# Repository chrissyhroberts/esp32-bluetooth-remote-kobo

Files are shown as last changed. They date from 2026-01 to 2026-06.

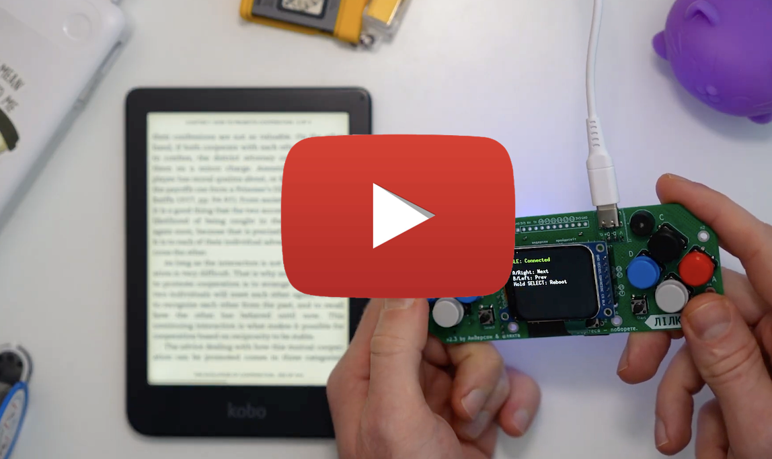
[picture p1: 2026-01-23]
img/lilka-kobo-demo-video.png

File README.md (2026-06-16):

# Kobo BLE Page Turner

A simple Bluetooth page-turning remote for Kobo e-readers built using an ESP32, two mechanical keyboard switches, and a rechargeable LiPo battery.

The device acts as a Bluetooth HID keyboard and sends left and right arrow key presses to a Kobo reader. It is designed as a compact handheld remote that can be comfortably operated using the index and middle fingers while reading.

Also works as a slide-clicker for presenting in powerpoint etc. on a laptop or phone. 

WhatsApp Image 2026-06-16 at 10 27 49
WhatsApp Image 2026-06-16 at 10 27 48 (1)

## Demo

https://github.com/user-attachments/assets/7c18b657-2313-463f-bc3e-a1ec03a47499

## Features

* Bluetooth Low Energy (BLE) HID keyboard
* Compatible with Kobo e-readers that support Bluetooth keyboards
* Two-button interface:

  * Next page
  * Previous page
* Rechargeable LiPo battery support
* USB charging via Adafruit HUZZAH32 Feather
* Mechanical keyboard switches for improved tactile feedback
* Open-source hardware and software
* Fully self-contained handheld design

## Hardware

### Current Build

| Component | Description |
| --- | --- |
| Microcontroller | Adafruit HUZZAH32 Feather ESP32 |
| Battery | 3.7V LiPo (150–500 mAh recommended) |
| Buttons | 2 × MX-compatible mechanical keyboard switches |
| Keycaps | Standard MX-compatible keycaps |
| Enclosure | Custom 3D printed enclosure |
| Charging | Integrated Feather LiPo charger |

### Wiring

| GPIO | Function |
| --- | --- |
| GPIO14 | Next page |
| GPIO27 | Previous page |

Connect each switch between the GPIO pin and GND.

```text
GPIO14 ---- Switch ---- GND

GPIO27 ---- Switch ---- GND
```

No external resistors are required because the firmware uses the ESP32's internal pull-up resistors.

### Battery

The current design uses a single-cell 3.7V LiPo battery connected directly to the Feather JST connector.

Recommended capacities:

| Capacity | Notes |
| --- | --- |
| 150 mAh  | Compact, preferred for final build |
| 300 mAh  | Good compromise |
| 500 mAh  | Longer runtime |
| 1200 mAh | Works but physically large |

## Enclosure

The enclosure is designed around:

* Adafruit HUZZAH32 Feather
* Two MX switches mounted in a side wall
* Small LiPo battery
* USB access for charging and firmware updates

The intended grip places one long side of the enclosure against the index and middle fingers, allowing page turns without changing grip.

```text
      SW1     SW2
       ↓       ↓

 ┌──────────────────┐
 │                  │
 │  Feather + LiPo  │
 │                  │
 └──────────────────┘
```

Current design goals:

* Approximately 80 × 32 × 20 mm
* Lightweight
* Rechargeable
* One-handed operation
* Easily printable without support

## Firmware

The firmware is written using Arduino and PlatformIO.

The device advertises as:

```text
KoboPageTurner
```

and appears to the Kobo as a Bluetooth keyboard.

### Building

```bash
python3 -m platformio run -e huzzah32
```

### Uploading

```bash
python3 -m platformio run -e huzzah32 -t upload
```

### Serial Monitor

```bash
python3 -m platformio device monitor -b 115200
```

## Pairing

1. Power on the device.
2. Open Bluetooth settings on the Kobo.
3. Search for:

```text
KoboPageTurner
```

4. Pair and connect.
5. Open a book and test page turns.

## Power Management

The current firmware remains continuously connected.

Planned behaviour:

```text
Button press
    ↓
Wake ESP32
    ↓
Start BLE
    ↓
Connect to Kobo
    ↓
Remain active
    ↓
5 minutes inactivity
    ↓
Deep sleep
```

This should allow excellent battery life even with a small 150 mAh LiPo cell.

## Development History

The project was initially prototyped using an ESP32-C3 SuperMini before being migrated to an Adafruit HUZZAH32 Feather to take advantage of:

* Integrated LiPo charging
* JST battery connector
* Simplified hardware
* Easier prototyping

## Acknowledgements

### Firmware

This project builds upon and adapts the work of:

* https://github.com/tkanov/esp32-bluetooth-remote-kobo

The original project targets the Lilka ESP32 platform and demonstrates BLE page turning for Kobo devices. This project adapts the concept for the Adafruit HUZZAH32 Feather and a custom handheld enclosure.

### Enclosure

The enclosure design was inspired by:

* https://www.thingiverse.com/thing:3824089

which provided the basis for Cherry MX switch mounting and plate geometry used during enclosure development.

## License

MIT License.

This repository contains original work together with adaptations of MIT-licensed open-source software and design concepts. Attribution to upstream projects is provided in the acknowledgements section.

## Future Work

* Deep sleep support
* Wake on button press
* Battery level monitoring
* Status LED indication
* Improved enclosure ergonomics
* Smaller PCB-based hardware revision
* Optional support for additional e-reader platforms

# Changelog

All notable changes to this project will be documented in this file.

The format is based on Keep a Changelog.

## [0.2.0] - 2026-06-13

### Added

* Migrated project to Adafruit HUZZAH32 Feather ESP32.
* Added support for LiPo battery operation using onboard JST connector.
* Added support for integrated USB charging via Feather hardware.
* Added custom 3D printed handheld enclosure.
* Added support for MX-compatible mechanical keyboard switches.
* Added serial debugging messages for button presses and BLE connection state.
* Added documentation and build instructions.

### Changed

* Replaced ESP32-C3 SuperMini hardware with HUZZAH32 Feather.
* Simplified hardware architecture by eliminating external charger modules.
* Updated button assignments:

  * GPIO14 → Next page
  * GPIO27 → Previous page
* Redesigned enclosure for side-mounted switch operation using index and middle fingers.
* Optimised device layout around Feather form factor and LiPo battery.

### Fixed

* Resolved BLE pairing and connection issues during migration from ESP32-C3.
* Confirmed compatibility with Kobo Bluetooth keyboard input.
* Verified HID arrow key transmission on HUZZAH32 platform.

## [0.1.0] - 2026-06-13

### Added

* Initial proof-of-concept implementation based on:

  * https://github.com/tkanov/esp32-bluetooth-remote-kobo
* BLE HID keyboard functionality.
* Kobo page-turn support using left and right arrow keys.
* ESP32-C3 SuperMini firmware build environment.
* PlatformIO build and upload workflow.
* Basic two-button operation:

  * Next page
  * Previous page
* BLE bonding and security configuration.
* Reboot button support.
* Serial status reporting.

### Hardware

* ESP32-C3 SuperMini.
* Two momentary push-buttons connected directly to GPIO inputs.
* USB-powered operation.

## Planned

### [0.3.0]

* Deep sleep support.
* Wake on button press.
* Automatic sleep after inactivity.
* Battery-life optimisation.
* Battery status indication.
* Improved enclosure ergonomics.
* Finalised printable enclosure design.

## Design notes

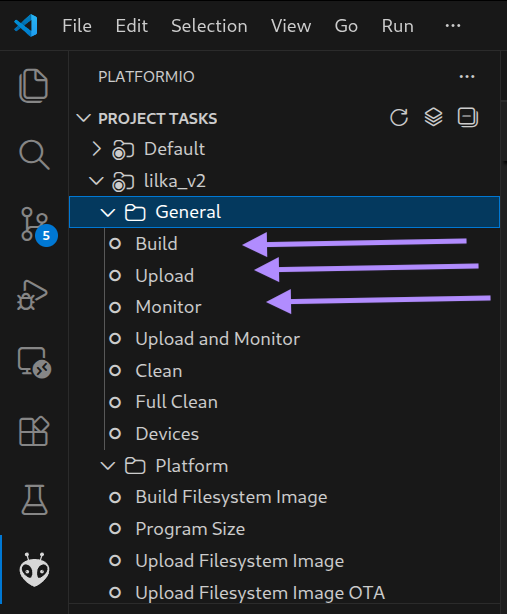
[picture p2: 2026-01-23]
img/vscode-platformio.png

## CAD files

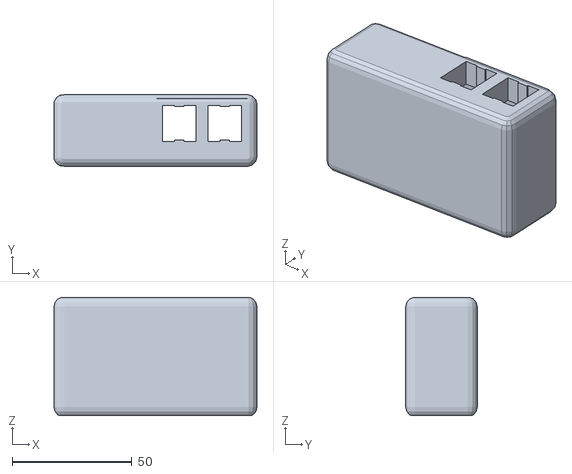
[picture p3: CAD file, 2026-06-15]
Enclosure_parametric.stl
84.9 x 29.9 x 49.4

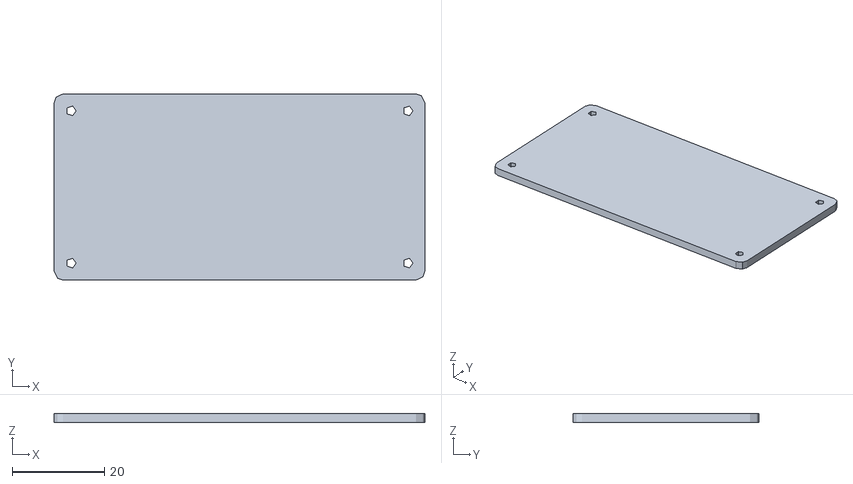
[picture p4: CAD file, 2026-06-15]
Enclosure_parametric_lid.stl
80.4 x 40.4 x 2.00

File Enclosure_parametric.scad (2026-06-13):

/* Kobo BLE Page Turner Enclosure
   Side-face MX switch version
   Hold with narrow long side against index/middle fingers.
*/

$fn = 48;

// ---------- Main dimensions ----------
case_w = 80;      // length
case_h = 40;      // width
case_d = 20;      // thickness / height

wall = 2;
corner_r = 5;

// ---------- MX side switch settings ----------
mx_cut = 14.2;
mx_spacing = 26;          // distance between switch centres along length
mx_z = 2;                 // vertical position on side face
switch_side_y = case_h/2; // switches on upper long side

// ---------- USB cutout on short end ----------
usb_w = 11;
usb_h = 7;
usb_x = case_w/2;

// ---------- Lid ----------
lid_thick = 2;
lid_gap = 0.35;
lip_h = 3;

// ---------- Helpers ----------
module rounded_box(w, h, d, r) {
    hull() {
        for (x=[-w/2+r, w/2-r])
        for (y=[-h/2+r, h/2-r])
            translate([x,y,0])
                cylinder(h=d, r=r, center=true);
    }
}

// MX cutout projected through side wall.
// Shape dimensions: x = switch width along case length,
// z = switch height, y = depth through wall.
module mx_side_cutout() {
    cube([mx_cut, wall + 8, mx_cut], center=true);
}

// ---------- Top shell ----------
module top_shell() {
    difference() {
        // outer body
        rounded_box(case_w, case_h, case_d, corner_r);

        // hollow interior, open from bottom
        translate([0,0,-wall])
            rounded_box(
                case_w - 2*wall,
                case_h - 2*wall,
                case_d,
                max(corner_r - wall, 1)
            );

        // side-face MX cutouts
        translate([-mx_spacing/2, switch_side_y, mx_z])
            mx_side_cutout();

        translate([ mx_spacing/2, switch_side_y, mx_z])
            mx_side_cutout();

        // USB cutout on right short end
        translate([usb_x, 0, -2])
            cube([wall + 3, usb_w, usb_h], center=true);
    }
}

// ---------- Bottom lid ----------
module bottom_lid() {
    union() {
        rounded_box(case_w, case_h, lid_thick, corner_r);

        translate([0,0,lid_thick/2 + lip_h/2])
        difference() {
            rounded_box(
                case_w - 2*wall - lid_gap,
                case_h - 2*wall - lid_gap,
                lip_h,
                max(corner_r - wall, 1)
            );

            rounded_box(
                case_w - 2*wall - 4,
                case_h - 2*wall - 4,
                lip_h + 1,
                max(corner_r - wall - 1, 1)
            );
        }
    }
}

// ---------- Build ----------
top_shell();

translate([0, 48, -case_d/2 + lid_thick/2])
    bottom_lid();

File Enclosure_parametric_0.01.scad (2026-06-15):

/*[Station]*/
rows=2;
columns=1;
// Could be made thinner but then you should add legs. Make sure the total height/thickness is 9 or more or else the switches will touch the ground.
caseThickness=9;
switch="MX"; // ["MX","ALPS"]
showSwitch=false;

/*[Legs]*/
legs=false;
legWidth=3;
legLength=3;
legHeight=6;

/*[Puzzle]*/
puzzle=false;
leftPuzzle=true;
rightPuzzle=true;
frontPuzzle=true;
backPuzzle=true;



/*[Danger zone]*/
// Measured from key cap center to key cap center
space=19.04;
plateLength=space*1.089;

/*[MX settings]*/
MX_cutXSize=14;
MX_cutYSize=15;
MX_notchX=4;
MX_notchY=0.50;

/*[ALPS settings]*/
ALPS_cutXSize=12.8;
ALPS_cutYSize=16.0;

function legZ(thickness,legHeight) = -(thickness*0.5+legHeight*0.5);

module MXSwitch(){
	// Awesome Cherry MX model created by gcb
	// Lib: Cherry MX switch - reference
	// Download here: https://www.thingiverse.com/thing:421524
	//  p=cherrySize/2+0.53;
	translate([0,0,13.2])
  rotate([0,0,-90])
		import("switch_mx.stl");
}

module ALPSSwitch(){
  // ALPS model created by qwelyt (me)
  // Lib: ALPS switch - reference
  // Download here: https://www.thingiverse.com/thing:3829342
  translate([0,0,-2])
  rotate([0,0,0])
  import("ALPS-switch.stl");
}

module leg(){
  cube([legWidth,legLength,legHeight],center=true);
}


module legs(thickness,rows,cols, row, col){
  x=(space*0.5-legWidth*0.5);
  y=(plateLength*0.5-legLength*0.5);
  z=legZ(thickness,legHeight);
  
  translate([0,0,0])translate([-x,-y,z])leg();
  translate([space*rows,0,0])translate([x,-y,z])leg();
  translate([0,space*cols,0])translate([-x,y,z])leg();
  translate([space*rows,space*cols,0])translate([x,y,z])leg();
  
}

module KeyPlate(w=space,l=plateLength,h=caseThickness,center=true){
	cube([w,l,h],center=center);
}

module MXCut(thickness,x,y,MX_notchX,MX_notchY){
  union(){
    difference(){
      cube([x,y,thickness+2],center=true);
      
      translate([0,y/2,0])
      cube([MX_notchX,MX_notchY,thickness+3],center=true);
      
      translate([0,-y/2,0])
      cube([MX_notchX,MX_notchY,thickness+3],center=true);
    }
  }
}

module ALPSCut(thickness){
  cube([ALPS_cutXSize,ALPS_cutYSize,thickness+2],center=true);
}

module puzzleCut(thickness,hook){
  size = hook ? 9 : 10;
  move = hook ? 1 : 0;
  difference(){
    translate([0,0,0])rotate([0,0,45])cube([size,size,thickness],center=true);
    
    translate([0,size*0.4,0])cube([size*2,size,thickness+2],center=true);
    
    translate([0,-((size*0.8)+move),0])cube([size*2,size,thickness+2],center=true);
  }
}

module plate(){
   union(){
    for(r=[0:rows-1]){
      for(c=[0:columns-1]){
        translate([space*r, space*c,0]){
          difference(){
            KeyPlate();
            if(switch == "MX"){
              MXCut(caseThickness,MX_cutXSize,MX_cutYSize,MX_notchX,MX_notchY*2);
            } else if(switch == "ALPS"){
              ALPSCut(caseThickness);
            } else {
              cube([space*0.8,space*0.8,caseThickness+2],center=true);
            }
          }
          if(showSwitch){
            if(switch == "MX"){
              #translate([0,0,caseThickness/2])MXSwitch();
            } else if(switch == "ALPS"){
              #translate([0,0,caseThickness/2])ALPSSwitch();
            } else {
              #translate([0,0,caseThickness/2])
              cube([space*0.8,space*0.8,caseThickness+2],center=true);
            }
          }
          
          
        }
      }
    }
  }
}

module build_swithes(){
  union(){
    if(puzzle){
      difference(){
        plate();
        if(backPuzzle){
          translate([0,-space*0.39,0])puzzleCut(caseThickness+2,false);
          
          translate([space*(rows-1),-space*0.39,0])puzzleCut(caseThickness+2,false);
        }
    
        if(rightPuzzle){
          translate([-space*0.346,0,0])rotate([0,0,-90])puzzleCut(caseThickness+2,false);
          
          translate([-space*0.346,space*(cols-1),0])rotate([0,0,-90])puzzleCut(caseThickness+2,false);
        }
      }
      
      if(frontPuzzle){
        translate([0,space*cols-space*0.3,0])puzzleCut(caseThickness,true);
        
        translate([space*(rows-1),space*cols-space*0.3,0])puzzleCut(caseThickness,true);
      }
      
      if(leftPuzzle){
        translate([space*rows-space*0.35,0,0])rotate([0,0,-90])puzzleCut(caseThickness,true);
        
        translate([space*rows-space*0.35,space*(cols-1),0])rotate([0,0,-90])puzzleCut(caseThickness,true);
      }
      
    } else {
      plate();
    }
 
    if(legs){
      legs(caseThickness,rows-1,cols-1,0,0);
    }
  }
}




case_w = 85;
case_h = 45;
case_d = 20;
wall = 2;
r = 4;

module rounded_cube(size=[70,40,20], r=4) {
    minkowski() {
        cube([
            size[0] - 2*r,
            size[1] - 2*r,
            size[2] - 2*r
        ], center=true);
        sphere(r=r);
    }
}

module hollow_body() {
    difference() {
        rounded_cube([case_w, case_h, case_d], r);

        translate([0,0,-wall])
            rounded_cube([
                case_w - 2*wall,
                case_h - 2*wall,
                case_d
            ], max(r-wall,1));
    }
}

module switch_holes_only() {
    for(rw=[0:rows-1]) {
        for(cl=[0:columns-1]) {
            translate([space*rw, space*cl, 6])
                MXCut(caseThickness + 4,
                      MX_cutXSize,
                      MX_cutYSize,
                      MX_notchX,
                      MX_notchY*2);
        }
    }
}

// ---------- Feather mount ----------
feather_w = 22.86;
feather_l = 50.8;
feather_hole_d = 2.6;      // clearance for M2-ish screw, tweak if needed
standoff_d = 5.5;
standoff_h = 12;
standoff_z = -case_d/2 + wall + standoff_h/2;

// Approximate mounting hole positions.
// Tune after a print if needed.
feather_hole_x = feather_l/2 - 2.54;
feather_hole_y = feather_w/2 - 2.54;

// Place Feather lengthwise in the case.
// Shift if USB is not aligned.
feather_x_offset = 2;
feather_y_offset = 0;

module feather_standoff(x, y) {
    translate([x + feather_x_offset, y + feather_y_offset, standoff_z])
    difference() {
        cylinder(h=standoff_h, d=standoff_d, center=true);
        cylinder(h=standoff_h + 1, d=feather_hole_d, center=true);
    }
}

module feather_mounts() {
    feather_standoff(-feather_hole_x, -feather_hole_y);
    feather_standoff( feather_hole_x, -feather_hole_y);
    feather_standoff(-feather_hole_x,  feather_hole_y);
    feather_standoff( feather_hole_x,  feather_hole_y);
}




// ---------- Lid screw mounts ----------
lid_screw_d = 2.2;       // hole in lid, clearance for M2
boss_hole_d = 1.6;       // pilot hole in case boss for M2 self-tapper
boss_d = 5.5;
boss_h = 17;

screw_x = case_w/2 - 6;
screw_y = case_h/2 - 6;

module screw_positions() {
    for (x=[-screw_x, screw_x])
    for (y=[-screw_y, screw_y])
        translate([x,y,0])
            children();
}

module case_screw_bosses() {
    screw_positions()
        translate([0,0,-case_d/2 + wall + boss_h/2])
        difference() {
            cylinder(h=boss_h, d=boss_d, center=true);
            cylinder(h=boss_h + 1, d=boss_hole_d, center=true);
        }
}

module lid_screw_holes() {
    screw_positions()
        cylinder(h=lid_thick + 1, d=lid_screw_d, center=true);
}


// ---------- USB slot ----------
// Micro USB on short end of HUZZAH32.
// Increase width/height if your cable plug is chunky.
usb_slot_w = 12;
usb_slot_h = 8;
usb_slot_z = -1;
usb_slot_x = case_w/2;

module usb_slot() {
    translate([usb_slot_x, feather_y_offset, usb_slot_z])
        cube([wall + 4, usb_slot_w, usb_slot_h], center=true);
}

module shell() {
    difference() {
        union() {
    hollow_body();

    translate([0,0,5])
        build_swithes();

    translate([0,-4,5])
        feather_mounts();

    case_screw_bosses();
}

        // cut only switch holes
        switch_holes_only();

        // clearance below switches
        translate([space/2, 0, -1])
            cube([space*1.8, plateLength*0.8, 10], center=true);

        // USB access slot on short edge
        translate([0,0,-2.5])usb_slot();
    }
}



// ---------- Lid ----------
lid_thick = 2;
lid_clearance = 0.6;   // increase if too tight
lid_r = r - wall;      // matches inner corner radius

lid_w = case_w - 2*wall - lid_clearance;
lid_h = case_h - 2*wall - lid_clearance;

module rounded_rect_2d(w, h, rad) {
    offset(r=rad)
        square([w - 2*rad, h - 2*rad], center=true);
}

module lid() {
    difference() {
        linear_extrude(height=lid_thick, center=true)
            rounded_rect_2d(lid_w, lid_h, lid_r);

        lid_screw_holes();
    }
}


//shell();

translate([0, 0, -case_d/2 + lid_thick/2])
translate([0,55,18])lid();

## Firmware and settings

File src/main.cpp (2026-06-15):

#include <Arduino.h>
#include <BleKeyboard.h>
#include <BLEDevice.h>
#include <BLESecurity.h>
#include "esp_sleep.h"

static const int NEXT_PIN = 14;
static const int PREV_PIN = 27;

static const uint32_t SLEEP_AFTER_MS = 5UL * 60UL * 1000UL;

BleKeyboard bleKeyboard("KoboPageTurner");

static uint32_t lastActivityMs = 0;

static void setupBleSecurityNoMitm() {
  auto *sec = new BLESecurity();

  sec->setAuthenticationMode(ESP_LE_AUTH_BOND);
  sec->setCapability(ESP_IO_CAP_NONE);
  sec->setKeySize(16);

  sec->setInitEncryptionKey(ESP_BLE_ENC_KEY_MASK | ESP_BLE_ID_KEY_MASK);
  sec->setRespEncryptionKey(ESP_BLE_ENC_KEY_MASK | ESP_BLE_ID_KEY_MASK);
}

static bool fell(int pin) {
  static uint32_t lastPressMs[40] = {0};

  if (digitalRead(pin) == LOW) {
    uint32_t now = millis();

    if (now - lastPressMs[pin] > 250) {
      lastPressMs[pin] = now;
      lastActivityMs = now;
      return true;
    }
  }

  return false;
}

static void goToSleep() {
  Serial.println("Sleeping after inactivity...");
  delay(100);

  // Wake when either button is pressed.
  // Buttons are INPUT_PULLUP, so press = LOW.
  esp_sleep_enable_ext0_wakeup((gpio_num_t)NEXT_PIN, 0);

  // Note: ESP32 ext0 supports one wake pin only.
  // For now, NEXT wakes the device.
  // We can add both buttons with ext1 if needed.

  esp_deep_sleep_start();
}

void setup() {
  Serial.begin(115200);
  delay(300);

  pinMode(NEXT_PIN, INPUT_PULLUP);
  pinMode(PREV_PIN, INPUT_PULLUP);

  lastActivityMs = millis();

  Serial.println("Starting HUZZAH32 Kobo BLE page turner...");
  Serial.println("First press after sleep wakes only; subsequent presses turn pages.");

  bleKeyboard.begin();
  setupBleSecurityNoMitm();

  Serial.println("Advertising as KoboPageTurner");
}

void loop() {
  static bool wasConnected = false;
  bool connected = bleKeyboard.isConnected();

  if (connected != wasConnected) {
    wasConnected = connected;
    Serial.println(connected ? "BLE connected" : "BLE advertising");
    lastActivityMs = millis();
  }

  if (fell(NEXT_PIN)) {
    bool connectedNow = bleKeyboard.isConnected();

    Serial.print("Next page pressed, connected=");
    Serial.println(connectedNow ? "YES" : "NO");

    if (connectedNow) {
      bleKeyboard.write(KEY_RIGHT_ARROW);
      Serial.println("Sent KEY_RIGHT_ARROW");
    } else {
      Serial.println("Not sent: BLE not connected");
    }
  }

  if (fell(PREV_PIN)) {
    bool connectedNow = bleKeyboard.isConnected();

    Serial.print("Previous page pressed, connected=");
    Serial.println(connectedNow ? "YES" : "NO");

    if (connectedNow) {
      bleKeyboard.write(KEY_LEFT_ARROW);
      Serial.println("Sent KEY_LEFT_ARROW");
    } else {
      Serial.println("Not sent: BLE not connected");
    }
  }

  if (millis() - lastActivityMs > SLEEP_AFTER_MS) {
    goToSleep();
  }

  delay(10);
}

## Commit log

2026-06-13 Working prototype for Huzzah
    [Enclosure_parametric.scad]
2026-06-15 Refactor enclosure SCAD and add STL exports
    Large refactor of the parametric enclosure OpenSCAD: replaced the previous Kobo/MX side-switch design with a new modular plate-based layout, added MX and ALPS cutouts, leg support, puzzle-piece cuts, feather (Feather HUZZAH) mounting bosses, lid with screw bosses and feather standoffs, USB slot, and numerous helper modules (rounded_cube, MXCut/ALPSCut, standoffs, etc.). Added STL exports (Enclosure_parametric.stl, Enclosure_parametric_lid.stl) and a 0.01-resolution SCAD variant. Also includes a small update to src/main.cpp. This commit restructures the model to be more configurable (rows/columns, switch type, legs, puzzles) and prepares printable S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
    [Enclosure_parametric.stl, Enclosure_parametric_0.01.scad, Enclosure_parametric_lid.stl]
